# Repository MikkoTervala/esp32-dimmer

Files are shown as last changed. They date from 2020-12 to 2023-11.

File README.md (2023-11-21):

# esp32-dimmer

PCB for the ESP32 WROOM module, with power supply and up to six mosfets for LED strip dimming.

# 2023 Model

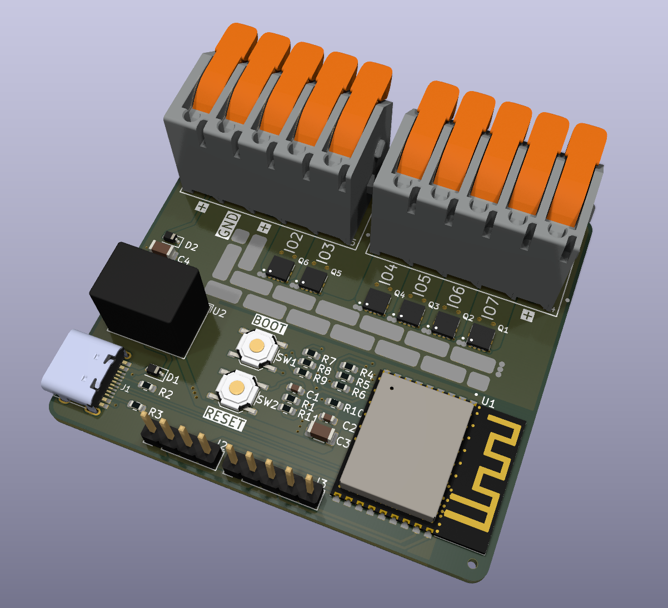
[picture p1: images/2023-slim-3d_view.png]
3D view

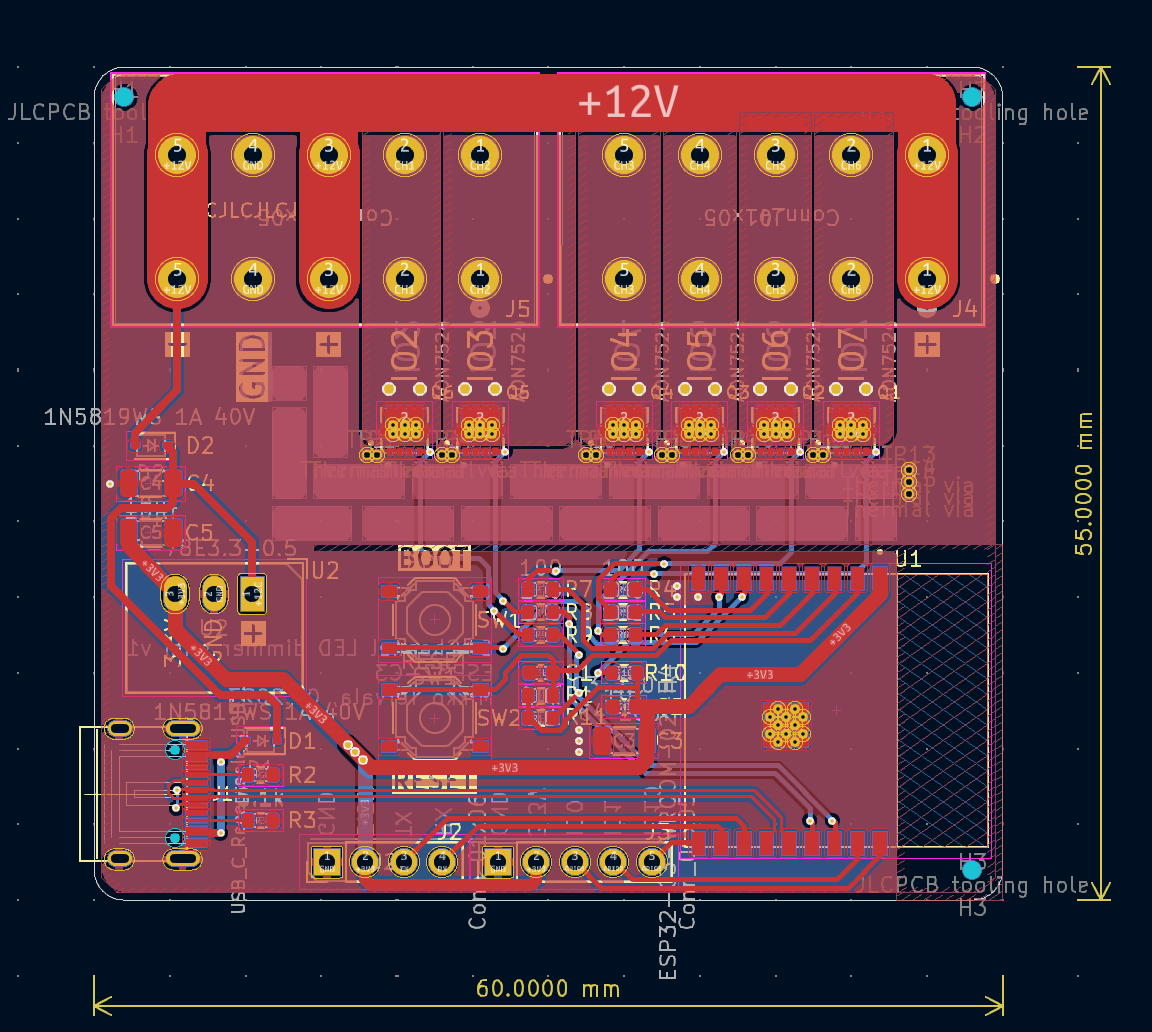
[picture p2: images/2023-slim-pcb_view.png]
PCB view


## Specifications

* Uses the ESP32-C3-WROOM-02-H4 microcontroller module
* Built in USB C connector for programming
* Designed to be made with SMD assembly
* 12 to 24V
* Designed for 5A single channel or 10A combined.

## Notes

* Ordering 10 PCB's with SMD assembly not including ESP32 cost 65€
* Ordering 10 ESP32-C3 modules and regulators cost 43€ 

## Next version ideas

* Add power LED
* Move 24V and GND pins to the middle of connector for shorter routing
* Expose all unused GPIO's as SMD test points

# 2020 Model

## Specifications

* 12 or 24V
* Designed for 5A single channel or 10A combined with a low cost 1 oz PCB.
* Can be used with ESP32-WROOM-32 module or the DOIT Esp32 DevKit available from china.
* Can be used with CUI VXO7803-500 DC-DC converter or with "mini power supply module 3A" available from china.
* Fits inside square european electrical box.

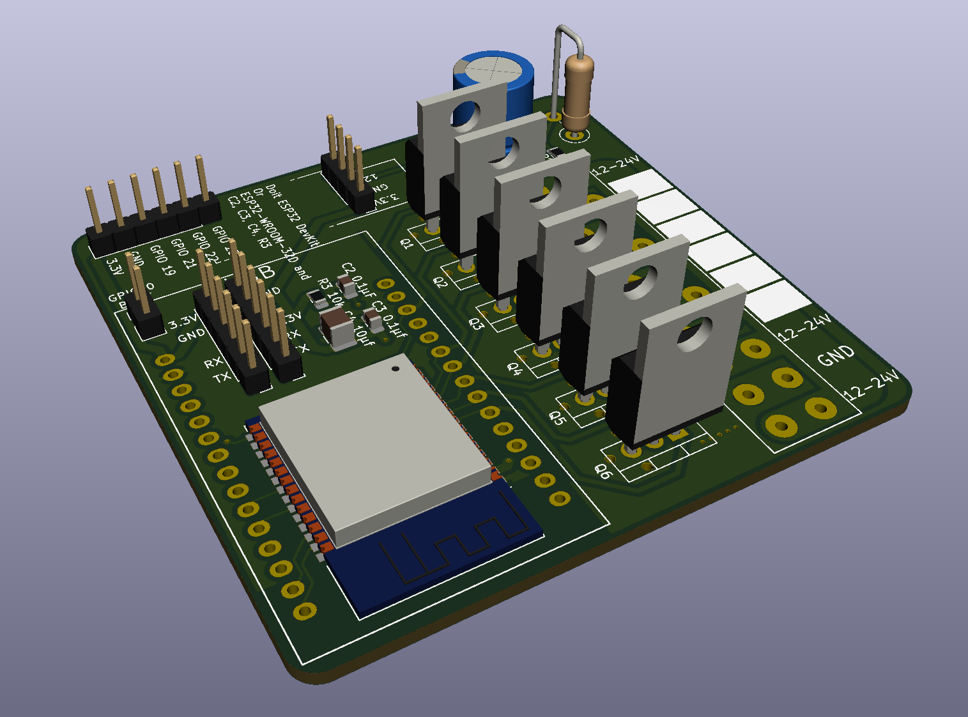
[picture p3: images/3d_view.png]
3D view

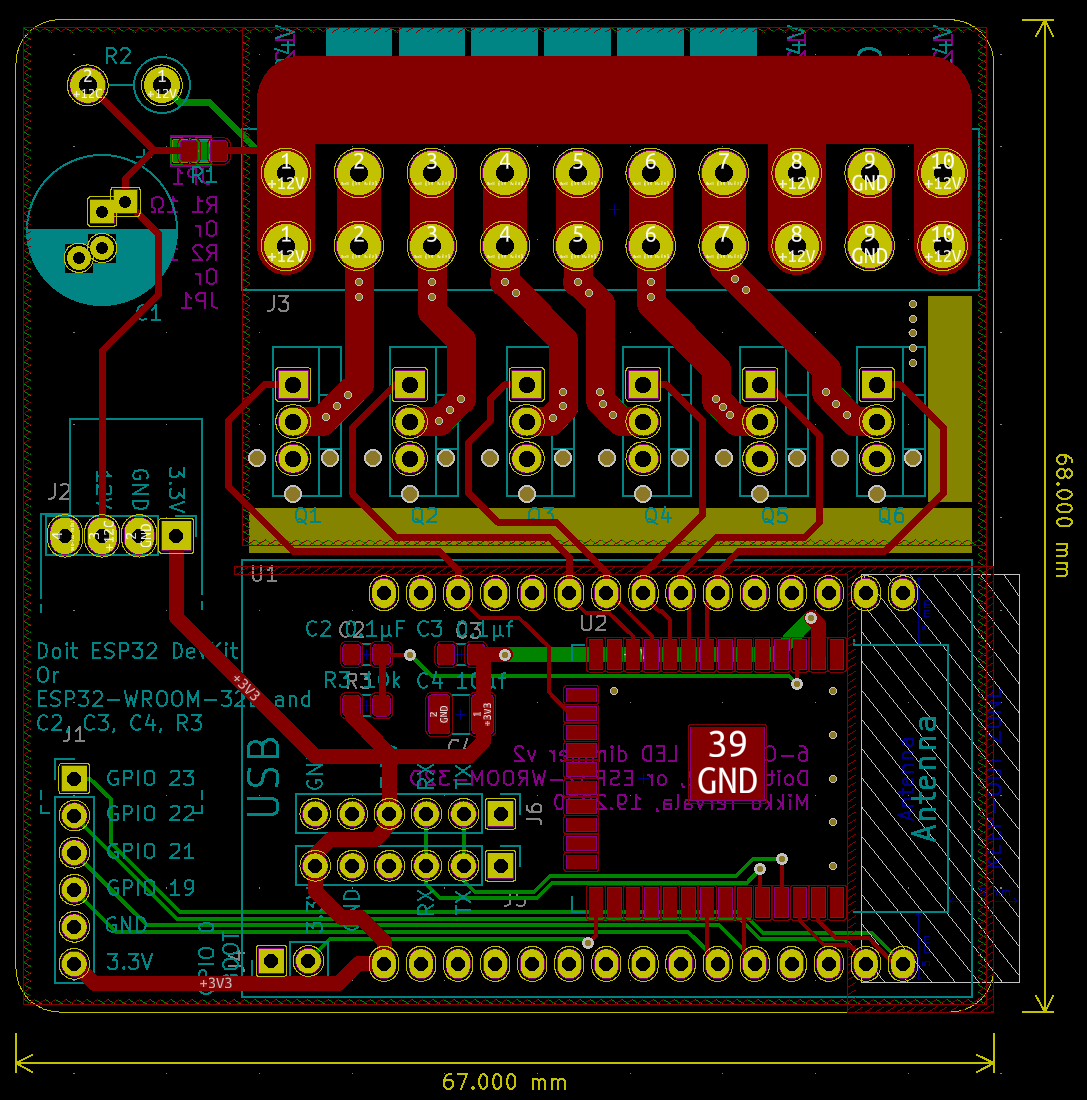
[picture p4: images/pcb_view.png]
PCB view


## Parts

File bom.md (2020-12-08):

# Dimmer BOM

| Part | Package | Designators | Quantity | Detail | Mouser Link |
|---|---|---|---|---|---|
| 5ohm resistor | `SMD:R_0805_2012` | R1 | 1 | Mutually exclusive with R2 and JP1 | [Mouser](https://www.mouser.fi/ProductDetail/Panasonic/ERJ-U06F5R10V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) |
| 10Kohm resistor | `SMD:R_0805_2012` | R3 | 1 | | [Mouser](https://www.mouser.fi/ProductDetail/ROHM-Semiconductor/SFR10EZPJ103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) |
| 100uF electrolytic capacitor 35V | `THT:CP_Radial_D7.5mmP2.5mm` | C1 | 1 | Voltage rating must be greater than input voltage | [Mouser](https://www.mouser.fi/ProductDetail/Nichicon/UHV1V101MED?qs=gGQEDQw8dtuoIXsrKRqhYA%3D%3D) |
| 0.1uF MLCC | `SMD:C_0805_2012` | C2, C3 | 2 | | [Mouser](https://www.mouser.fi/ProductDetail/Samsung-Electro-Mechanics/CL21B104KBCNNWC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) |
| 10uF MLCC | `SMD:C_1210_3225` | C4 | 1 | | [Mouser](https://www.mouser.fi/ProductDetail/Samsung-Electro-Mechanics/CL32A106KAULNNE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) |
| PSMN2R0-30PL,127 N-channel mosfet 30V | `TO_SOT_THT:TO-220-3_Vertical` | Q1-6 | 1-6 | Voltage rating must be greater than input voltage | [Mouser](https://www.mouser.fi/ProductDetail/Nexperia/PSMN2R0-30PL127?qs=HnaUIVfgVjA%2FKafwq0%2FtuQ%3D%3D) |
| VXO7803-500 DC/DC converter 36VMAX -> 3.3V | - | J2 | 1 | 500mA is enough for the microcontroller | [Mouser](https://www.mouser.fi/ProductDetail/CUI-Inc/VXO7803-500?qs=HXFqYaX1Q2yRMiJy6n36SQ%3D%3D) |
| SPTAF 1/10-5,0-LL or -EL 10 position connector | - | J3 | 0-1 | Wires can just be soldered to the pcb. Expensive  | [Mouser](https://www.mouser.fi/ProductDetail/Phoenix-Contact/1862495?qs=tlR8i4ZVbUei8C1X%2Fpz9ww%3D%3D) |
| ESP32-WROOM-32E | - | U2 | 1 | Mutually exclusive with U1 | [Mouser](https://www.mouser.fi/ProductDetail/Espressif-Systems/ESP32-WROOM-32EM113EH2800PH3Q0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) |

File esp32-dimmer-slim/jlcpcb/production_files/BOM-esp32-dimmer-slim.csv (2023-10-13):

Comment | Designator | Footprint | LCSC
C4 10µf | C3,C4,C5 | C_1206_3216Metric | C13585
1µF | C1 | C_0603_1608Metric | C15849
USB_C_Receptacle_USB2.0 | J1 | TYPE-C-31-M-12 | C165948
1N5819WS 1A 40V | D1,D2 | D_SOD-323 | C191023
C3 220nf | C2 | C_0603_1608Metric | C21120
100 | R4,R5,R6,R7,R8,R9 | R_0603_1608Metric | C22775
5.1k | R2,R3 | R_0603_1608Metric | C23186
10k | R1,R10,R11 | R_0603_1608Metric | C25804
BOOT | SW1,SW2 | SW_Push_1P1T_XKB_TS-1187A | C318884
AON7524 | Q1,Q2,Q3,Q4,Q5,Q6 | TRANS_AON7403 | C431195

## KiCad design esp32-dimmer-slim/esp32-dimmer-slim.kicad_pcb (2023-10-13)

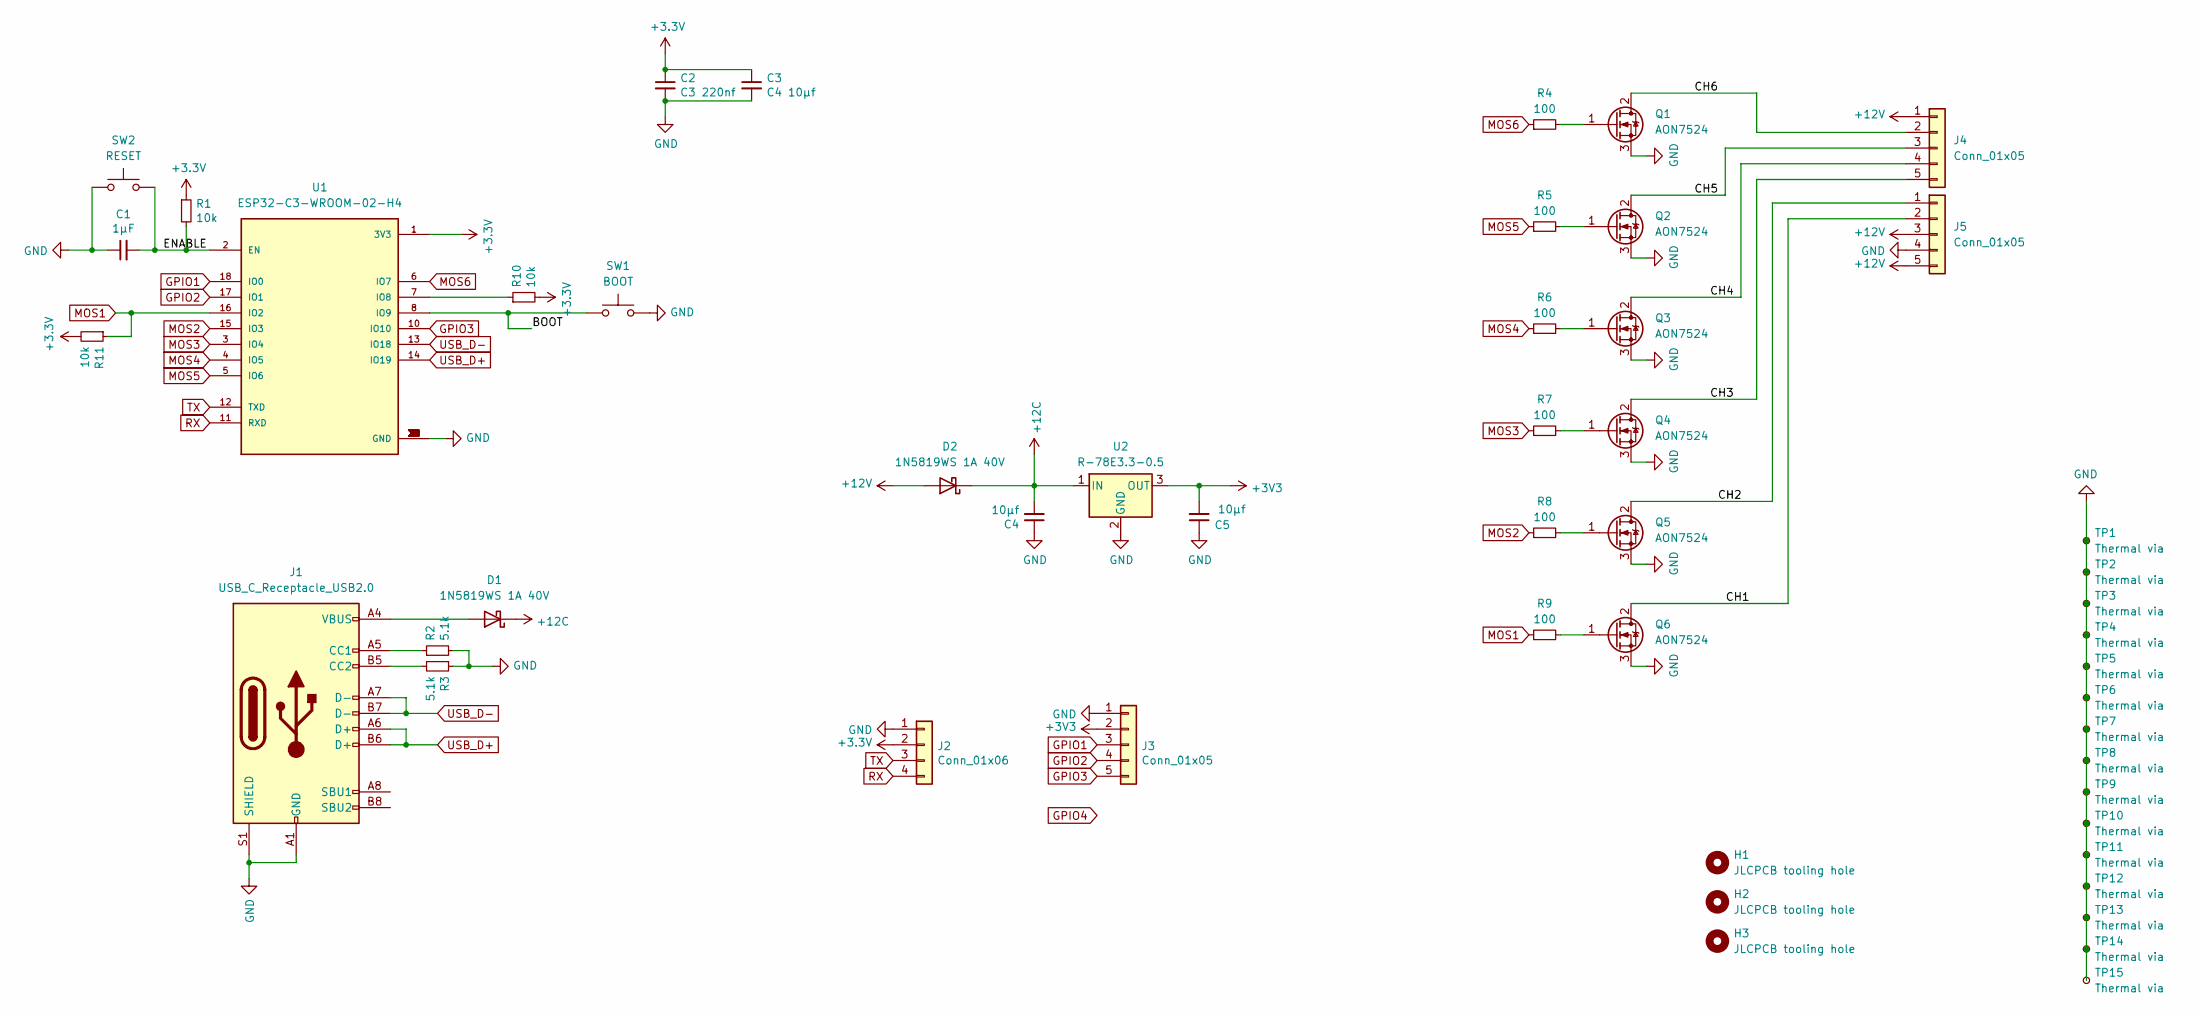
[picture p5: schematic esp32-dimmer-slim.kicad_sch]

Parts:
C1: 1µF; C_0603_1608Metric; LCSC Part # C15849
C2: C3 220nf; C_0603_1608Metric; LCSC Part # C21120
C3: C4 10µf; C_1206_3216Metric; LCSC Part # C13585
C4, C5: 10µf; C_1206_3216Metric; LCSC Part # C13585
D1, D2: 1N5819WS 1A 40V; D_SOD-323; LCSC Part # C191023
H1, H2, H3: JLCPCB tooling hole
J1: USB_C_Receptacle_USB2.0; TYPE-C-31-M-12; LCSC Part # C165948
J2: Conn_01x06; PinHeader_1x04_P2.54mm_Vertical
J3: Conn_01x05; PinHeader_1x05_P2.54mm_Vertical
J4, J5: Conn_01x05; CONN_2604-1105_WAG
Q1, Q2, Q3, Q4, Q5, Q6: AON7524; TRANS_AON7403; LCSC Part # C431195
R1, R10, R11: 10k; R_0603_1608Metric; LCSC Part # C25804
R2, R3: 5.1k; R_0603_1608Metric; LCSC Part # C23186
R4, R5, R6, R7, R8, R9: 100; R_0603_1608Metric; LCSC Part # C22775
SW1: BOOT; SW_Push_1P1T_XKB_TS-1187A; LCSC Part # C318884
SW2: RESET; SW_Push_1P1T_XKB_TS-1187A; LCSC Part # C318884
TP1, TP2, TP3, TP4, TP5, TP6, TP7, TP8, TP9, TP10, TP11, TP12, TP13, TP14, TP15: Thermal via; thermal via
U1: ESP32-C3-WROOM-02-H4; MODULE_ESP32-C3-WROOM-02-H4; LCSC Part # C2934560
U2: R-78E3.3-0.5; Converter_DCDC_RECOM_R-78E-0.5_THT

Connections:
+12C: C4.2, D1.1 (K), D2.1 (K), U2.1 (IN)
+12V: D2.2 (A), J4.1, J5.3, J5.5
/BOOT: SW1.1, U1.8 (IO9)
/CH1: J5.2, Q6.2 (D)
/CH2: J5.1, Q5.2 (D)
/CH3: J4.5, Q4.2 (D)
/CH4: J4.4, Q3.2 (D)
/CH5: J4.3, Q2.2 (D)
/CH6: J4.2, Q1.2 (D)
/ENABLE: C1.2, R1.2, SW2.2, U1.2 (EN)
GND: C1.1, C2.2, C3.2, C4.1, C5.1, J1.A1 (GND), J1.A12 (GND), J1.B1 (GND), J1.B12 (GND), J1.S1 (SHIELD), J2.1, J3.1, J5.4, Q1.3 (S), Q2.3 (S), Q3.3 (S), Q4.3 (S), Q5.3 (S), Q6.3 (S), R2.2, R3.1, SW1.2, SW2.1, TP1.1, TP2.1, TP3.1, TP4.1, TP5.1, TP6.1, TP7.1, TP8.1, TP9.1, TP10.1, TP11.1, TP12.1, TP13.1, TP14.1, TP15.1, U1.9 (GND), U1.19 (GND), U1.20 (GND), U1.21 (GND), U1.22 (GND), U1.23 (GND), U1.24 (GND), U1.25 (GND), U1.26 (GND), U1.27 (GND), U1.28 (GND), U1.29 (GND), U1.30 (GND), U1.31 (GND), U1.32 (GND), U1.33 (GND), U1.34 (GND), U1.35 (GND), U1.36 (GND), U1.37 (GND), U1.38 (GND), U1.39 (GND), U2.2 (GND)
GPIO1: J3.3, U1.18 (IO0)
GPIO2: J3.4, U1.17 (IO1)
GPIO3: J3.5, U1.10 (IO10)
MOS1: R9.1, R11.1, U1.16 (IO2)
MOS2: R8.1, U1.15 (IO3)
MOS3: R7.1, U1.3 (IO4)
MOS4: R6.1, U1.4 (IO5)
MOS5: R5.1, U1.5 (IO6)
MOS6: R4.1, U1.6 (IO7)
unnamed: D1.2 (A), J1.A4 (VBUS), J1.A9 (VBUS), J1.B4 (VBUS), J1.B9 (VBUS)
unnamed: J1.A5 (CC1), R2.1
unnamed: J1.B5 (CC2), R3.2
unnamed: Q1.1 (G), R4.2
unnamed: Q2.1 (G), R5.2
unnamed: Q3.1 (G), R6.2
unnamed: Q4.1 (G), R7.2
unnamed: Q5.1 (G), R8.2
unnamed: Q6.1 (G), R9.2
unnamed: R10.1, U1.7 (IO8)
RX: J2.4, U1.11 (RXD)
TX: J2.3, U1.12 (TXD)
USB_D+: J1.A6 (D+), J1.B6 (D+), U1.14 (IO19)
USB_D-: J1.A7 (D-), J1.B7 (D-), U1.13 (IO18)

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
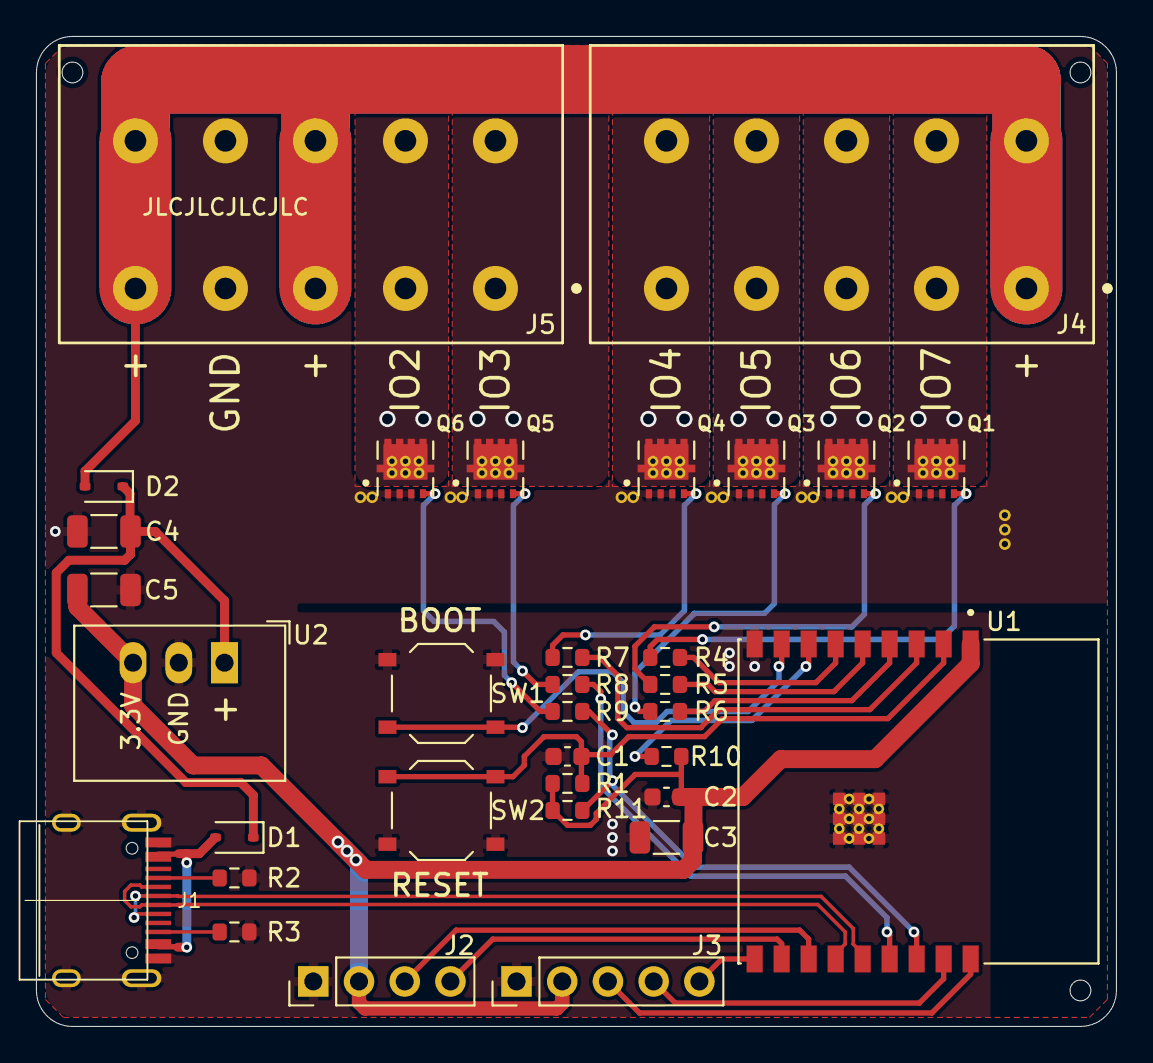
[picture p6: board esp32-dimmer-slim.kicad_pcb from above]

Board: 2 copper layers, 60.0 x 55.0 mm, 51 parts (0 on the bottom side), 35 nets.

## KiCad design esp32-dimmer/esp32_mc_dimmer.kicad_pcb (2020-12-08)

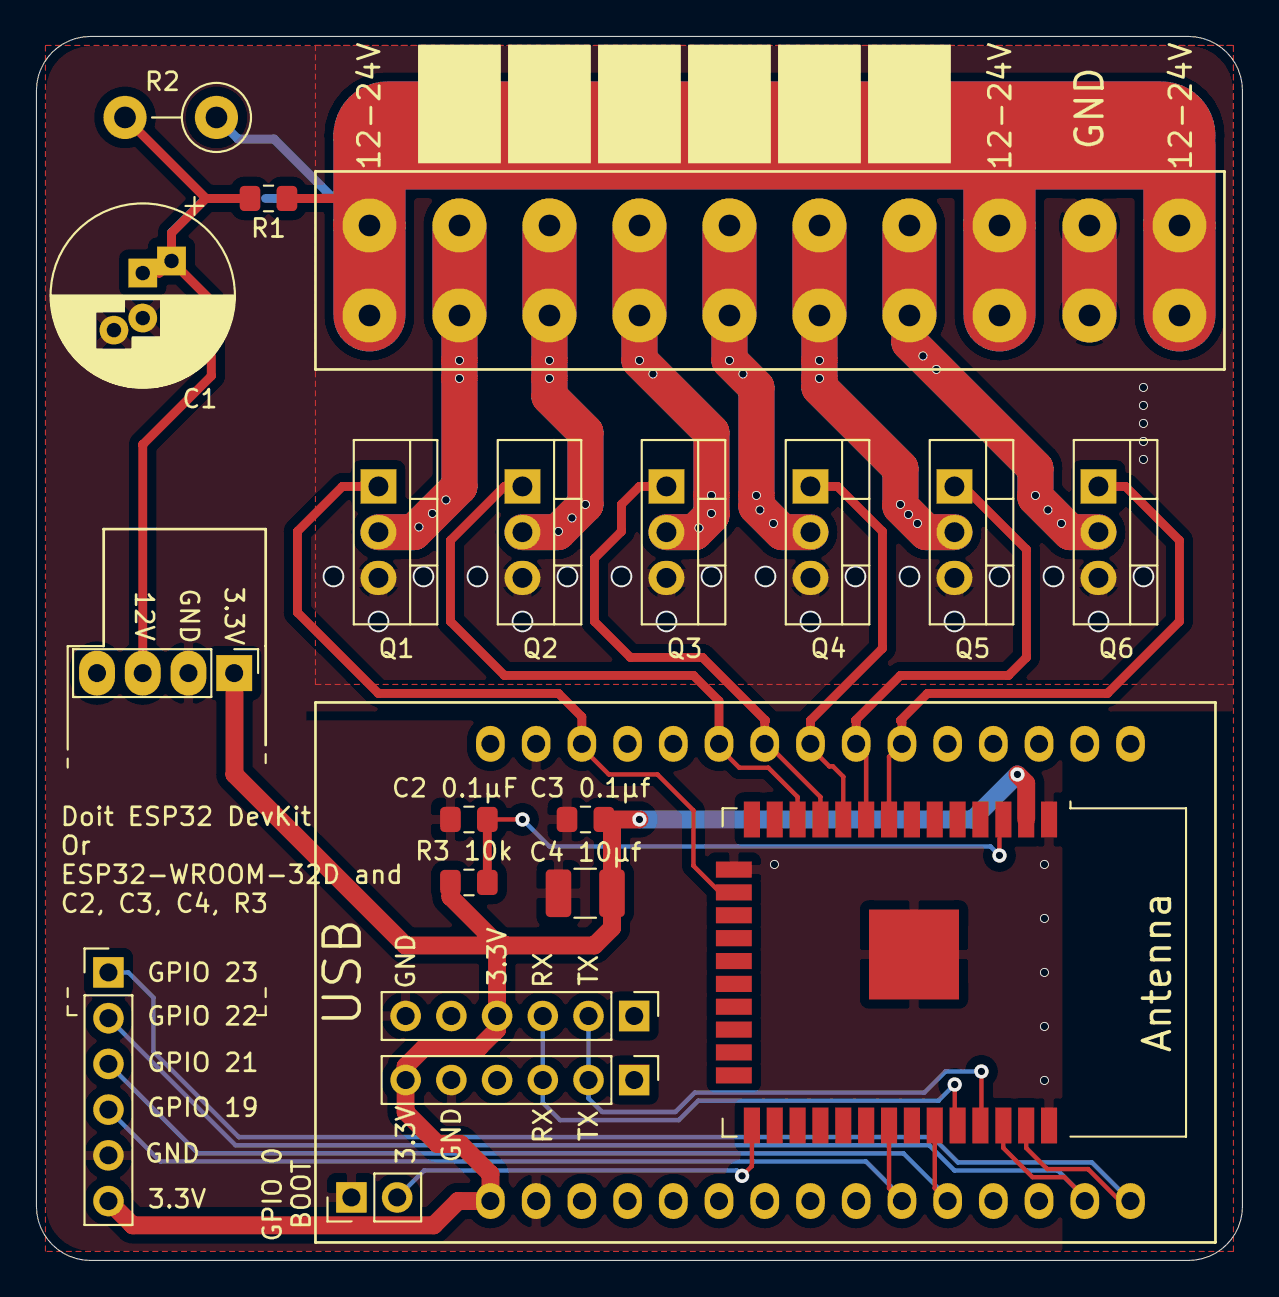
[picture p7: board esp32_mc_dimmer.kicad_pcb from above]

Board: 2 copper layers, 67.0 x 68.0 mm, 22 parts (1 on the bottom side), 24 nets.

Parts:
C1: C_Small; CP_Radial_D10.0mm_P2.50mm_P5.00mm
C2: C2 0.1µF; C_0805_2012Metric_Pad1.15x1.40mm_HandSolder
C3: C3 0.1µf; C_0805_2012Metric_Pad1.15x1.40mm_HandSolder
C4: C4 10µf; C_1210_3225Metric_Pad1.42x2.65mm_HandSolder
J1, J5, J6: Conn_01x06; PinHeader_1x06_P2.54mm_Vertical
J2: Conn_01x04; 4pin_reg_con
J3: Conn_01x10; Phoenix_SPTAF_1_10-5,0-EL
J4: Conn_01x02; PinHeader_1x02_P2.54mm_Vertical
JP1: Jumper_NO_Small; SolderJumper-2_P1.3mm_Open_TrianglePad1.0x1.5mm
Q1, Q2, Q3, Q4, Q5, Q6: BUZ11; TO-220-3_Vertical
R1: R_Small; R_0805_2012Metric_Pad1.15x1.40mm_HandSolder
R2: R_Small; R_Axial_DIN0411_L9.9mm_D3.6mm_P5.08mm_Vertical
R3: R3 10k; R_0805_2012Metric_Pad1.15x1.40mm_HandSolder
U1: Doit_ESP32
U2: ESP32-WROOM-32

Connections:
+3V3: C3.1, C4.1, J1.6, J2.1, J5.6, J6.4, R3.1, U1.1, U2.2
+12C: C1.1, J2.3, JP1.1, R1.2, R2.2
+12V: J3.1, J3.8, J3.10, JP1.2, R1.1, R2.1
GND: C1.2, C2.1, C3.2, C4.2, J1.5, J2.2, J3.9, J4.1, J5.5, J6.6, Q1.3, Q2.3, Q3.3, Q4.3, Q5.3, Q6.3, U1.2, U1.29, U2.1, U2.15, U2.38, U2.39
GPIO1: J1.1, U1.15, U2.37
GPIO2: J1.2, U1.14, U2.36
GPIO3: J1.3, U1.11, U2.33
GPIO4: J1.4, U1.10, U2.31
MOS1: Q1.1, U1.28, U2.16
MOS2: Q2.1, U1.25, U2.12
MOS3: Q3.1, U1.24, U2.11
MOS4: Q4.1, U1.23, U2.10
MOS5: Q5.1, U1.22, U2.9
MOS6: Q6.1, U1.21, U2.8
unnamed: C2.2, R3.2, U2.3
unnamed: J3.2, Q1.2
unnamed: J3.3, Q2.2
unnamed: J3.4, Q3.2
unnamed: J3.5, Q4.2
unnamed: J3.6, Q5.2
unnamed: J3.7, Q6.2
unnamed: J4.2, U2.25
RX: J5.3, J6.3, U2.34
TX: J5.2, J6.2, U2.35

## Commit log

2020-12-08 add bom (#1)
    * add bom
    * fix bom
    * quick bom hotfix
2020-12-08 Add new psu module and improve power layout
    [esp32_mc_dimmer.kicad_pcb, esp32_mc_dimmer.sch]
2020-12-08 Update gerber files
    [esp32_mc_dimmer-B_Cu.gbr, esp32_mc_dimmer-B_Mask.gbr, esp32_mc_dimmer-B_Paste.gbr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]
2020-12-08 Change resistor to lower inrush
    [esp32_mc_dimmer.kicad_pcb, esp32_mc_dimmer.sch]
2023-10-13 Update gitignore for new version of kicad
2023-10-13 Add 2023 model
    [BOM-esp32-dimmer-slim.csv, esp32-dimmer-slim.kicad_pcb, esp32-dimmer-slim.kicad_sch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]
